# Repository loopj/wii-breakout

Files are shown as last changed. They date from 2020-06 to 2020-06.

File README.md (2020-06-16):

# Wii Motherboard Breakout PCB

Wii motherboard breakout board for USB, Bluetooth, GameCube controllers, A/V, and RST lines.

This is designed to be permanently mounted to a (trimmed) Wii motherboard to give access to peripheral data lines without having to worry about breaking small wires. I designed this allow me to rapidly prototype "daughterboard" peripheral PCBs without having to de-solder/re-solder.

Useful for prototyping, or for permanent installation on Wii projects which are mounted with the CPU/GPU facing up (probably not most portables).

## Features
- Pads aim to be as close to onboard vias as possible
- Designed to lay flush with 4-layer Wii motherboards
- Cutout for capacitor (C56)
- Can be screw mounted (M2 or M2.5 screws), glued, or soldered
- Castellated mounting holes
- Footprints for vertical JST-SH headers
- Breaks out:
    - USB (D-, D+)
    - Audio (L, R, GND)
    - Component/RGB Video (Y, Pb, Pr, GND)
    - Bluetooth (D1, D2)
    - GameCube Controllers x4 (SI line)
    - Reset Line

## Gerber Files

See [releases](https://github.com/loopj/wii-breakout/releases).

## Order from OSH Park

https://oshpark.com/shared_projects/xyI6Kvkf

## Photos
### Board photo
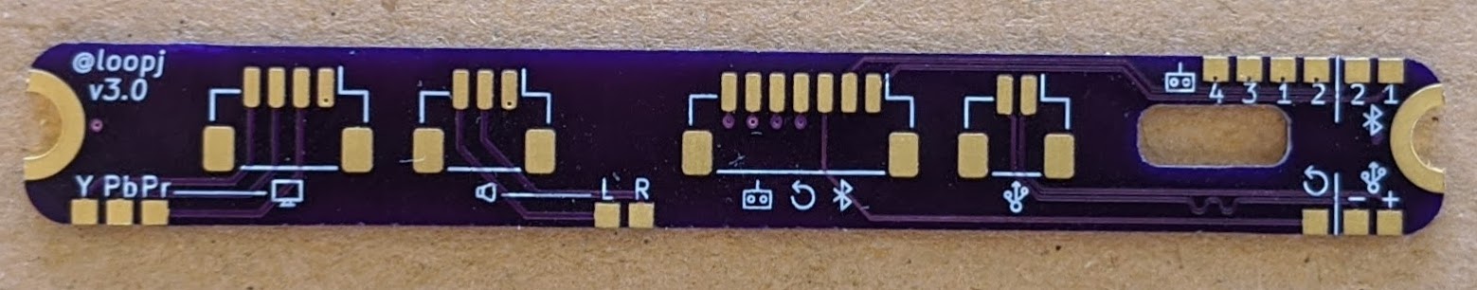
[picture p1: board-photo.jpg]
Board photo


### Motherboard placement
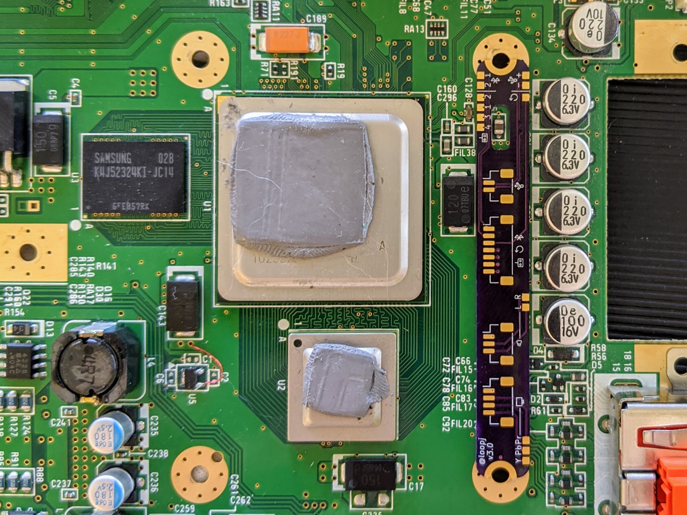
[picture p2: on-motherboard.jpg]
Board on motherboard


## PCB renders
### Front
Front of PCB

### Back
Back of PCB

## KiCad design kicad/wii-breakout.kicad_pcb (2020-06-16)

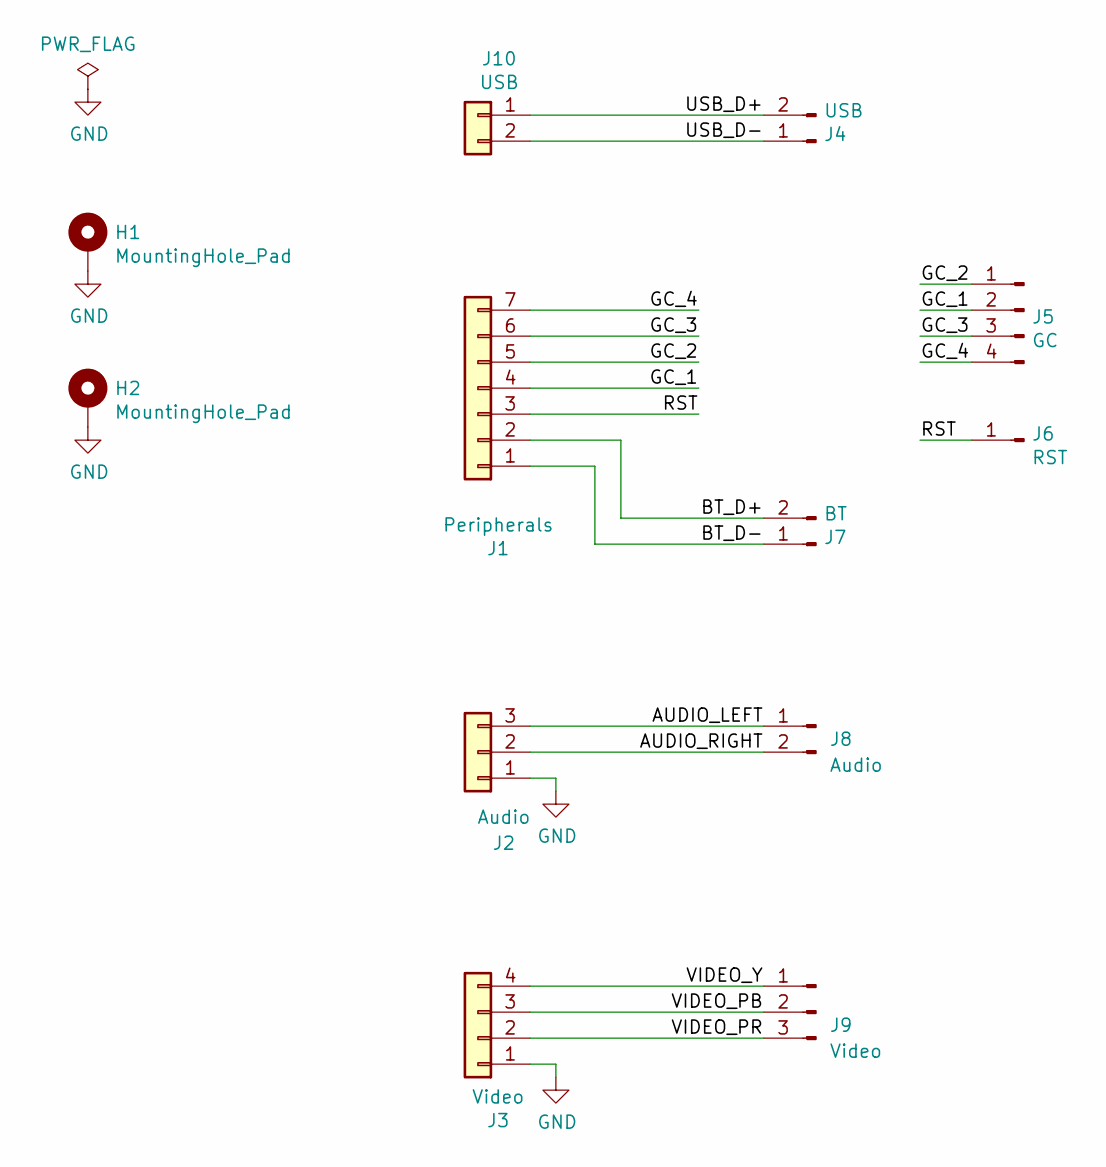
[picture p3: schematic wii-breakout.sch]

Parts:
H1, H2: MountingHole_Pad; MountingHole_2.7mm_M2.5_ISO14580_Pad
J1: Peripherals; JST_SH_BM07B-SRSS-TB_1x07-1MP_P1.00mm_Vertical; MPN BM09B-SRSS-TB(LF)(SN)
J2: Audio; JST_SH_BM03B-SRSS-TB_1x03-1MP_P1.00mm_Vertical; MPN BM03B-SRSS-TB(LF)(SN)
J3: Video; JST_SH_BM04B-SRSS-TB_1x04-1MP_P1.00mm_Vertical; MPN BM04B-SRSS-TB(LF)(SN)
J4: USB; TestPoint_2Pads_2.0x1.0mm
J5: GC; TestPoint_4Pads_2.0x1.0mm
J6: RST; TestPoint_Pad_2.0x1.0mm
J7: BT; TestPoint_2Pads_2.0x1.0mm
J8: Audio; TestPoint_2Pads_2.0x1.0mm
J9: Video; TestPoint_3Pads_2.0x1.0mm
J10: USB; JST_SH_BM02B-SRSS-TB_1x02-1MP_P1.00mm_Vertical

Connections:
/AUDIO_LEFT: J2.3, J8.1
/AUDIO_RIGHT: J2.2, J8.2
/BT_D+: J1.2, J7.2
/BT_D-: J1.1, J7.1
/GC_1: J1.4, J5.2
/GC_2: J1.5, J5.1
/GC_3: J1.6, J5.3
/GC_4: J1.7, J5.4
/RST: J1.3, J6.1
/USB_D+: J4.2, J10.1
/USB_D-: J4.1, J10.2
/VIDEO_PB: J3.3, J9.2
/VIDEO_PR: J3.2, J9.3
/VIDEO_Y: J3.4, J9.1
GND: H1.1, H2.1, J2.1, J3.1

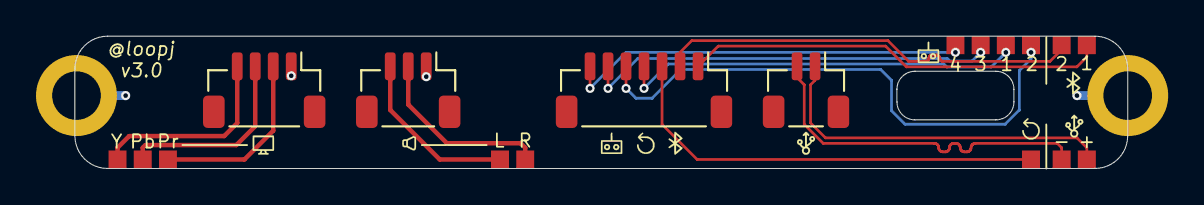
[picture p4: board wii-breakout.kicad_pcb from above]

Board: 2 copper layers, 58.5 x 7.4 mm, 12 parts (0 on the bottom side), 15 nets.

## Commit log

2020-03-26 Shrink the board
    [wii-breakout.kicad_pcb, wii-breakout.sch]
2020-06-16 v3.0 - minimal size, cutout for mobo cap, split USB from data header, reorder GC lines to match mobo
    [wii-breakout.kicad_pcb, wii-breakout.sch]
